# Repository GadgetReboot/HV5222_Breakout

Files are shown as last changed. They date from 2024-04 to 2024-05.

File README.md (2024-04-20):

# HV5222_Breakout
HV5222 32 bit shift register breakout board
<BR><BR>
Shield: [][cc-by-sa]

This work is licensed under a
[Creative Commons Attribution-ShareAlike 4.0 International License][cc-by-sa].

[][cc-by-sa]

[cc-by-sa]: http://creativecommons.org/licenses/by-sa/4.0/
[cc-by-sa-image]: https://licensebuttons.net/l/by-sa/4.0/88x31.png
[cc-by-sa-shield]: https://img.shields.io/badge/License-CC%20BY--SA%204.0-lightgrey.svg

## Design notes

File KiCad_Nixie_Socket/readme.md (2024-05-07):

This is the KiCad schematic for the IN-12 nixie tube breakout board and a pcb footprint for the nixie socket, which uses individual nixie socket pins available on ebay/AliExpress etc.  The pcb for the breakout board needs to be re-designed due to errors in the original.

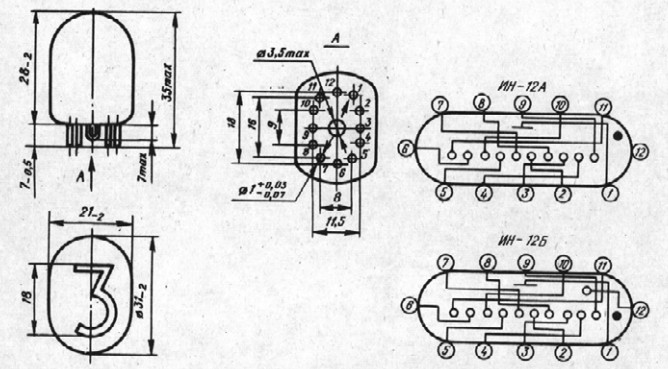
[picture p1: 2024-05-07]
KiCad_Nixie_Socket/pinout.jpg

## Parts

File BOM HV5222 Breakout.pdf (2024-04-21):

HV5222 Breakout BOM

Item # | Reference Designator | Qty | Manufacturer | Mfg Part # | Description / Value | Package/Footprint | Type | Instructions / Notes
1 | C3 | 1 | Samsung | CL21B104KBCNNWC | CAP CER 0.1UF 50V X7R 0805 | 0805 | SMD
2 | C1 C2 | 2 | Samsung | CL21B105KBFNNNE | CAP CER 1UF 50V X7R 0805 | 0805 | SMD
3 | D1 | 1 | SMC Diode Solutions | SS16 | 60V, 1A, SMA, DIODE SCHOTTKY | SMA | SMD
4 | J2 | 0 | | | | | | Do Not Install - User shall decide how to mount
5 | J1 J4 | 0 | | | | | | Do Not Install - User shall decide how to mount
6 | J3 | 0 | | | | | | Do Not Install - User shall decide how to mount
7 | L1 | 1 | Taiyo Yuden | NR6045T220M | FIXED IND 22UH 1.5A 149.5MOHM | Non Standard | SMD
8 | Q1 Q2 Q3 | 3 | Diotec Semiconductor | MMBT3904 | TRANS NPN 40V 200MA SOT23-3 | SOT23 | SMD
9 | R4 R7 R10 R12 | 4 | Panasonic | ERJ-6GEYJ472V | RES SMD 4K7 OHM 5% 1/8W 0805 | 0805 | SMD
10 | R2 | 1 | Panasonic | ERJ-6ENF1052V | RES SMD 10.5K OHM 1% 1/8W 0805 | 0805 | SMD
11 | R1 R3 R5 R6 R8 R9 R11 | 7 | Panasonic | ERJ-6ENF9102V | RES SMD 91K OHM 1% 1/8W 0805 | 0805 | SMD
12 | U1 | 1 | Diodes Incorporated | AP3012KTR-G1 | IC REG BOOST ADJ 500MA | SOT23-5 | SMD
13 | U2 | 1 | Microchip | HV5222PJ-G | IC 32BIT SRL PARALLEL 220V 44PLC | 44PLCC | SMD

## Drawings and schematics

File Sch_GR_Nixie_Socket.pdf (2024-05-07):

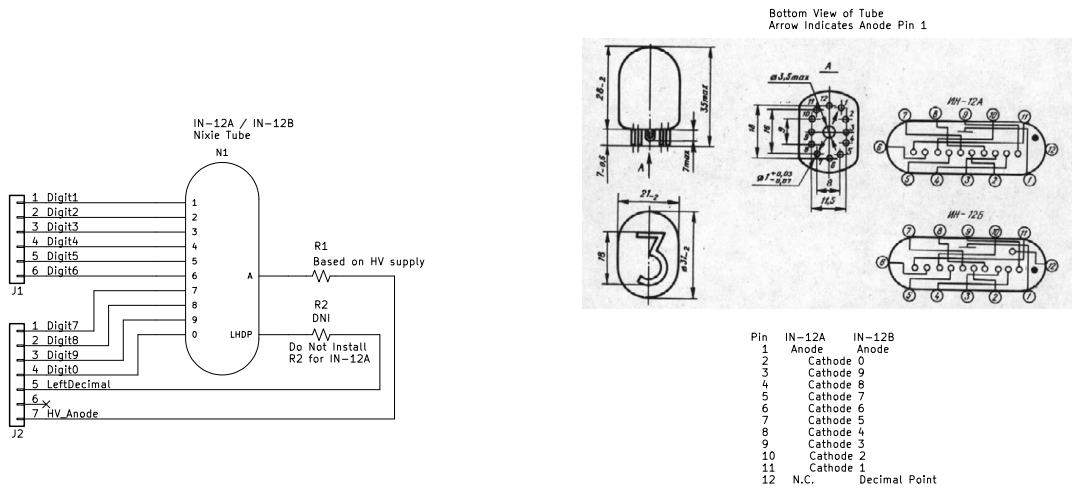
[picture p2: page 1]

https://github.com/GadgetReboot/HV5222_Breakout
https://www.youtube.com/gadgetreboot
File: GR_Nixie_Socket.sch Sheet: / Gadget Reboot

Id: 1/1 Title: Nixie Tube Socket IN-12A/B

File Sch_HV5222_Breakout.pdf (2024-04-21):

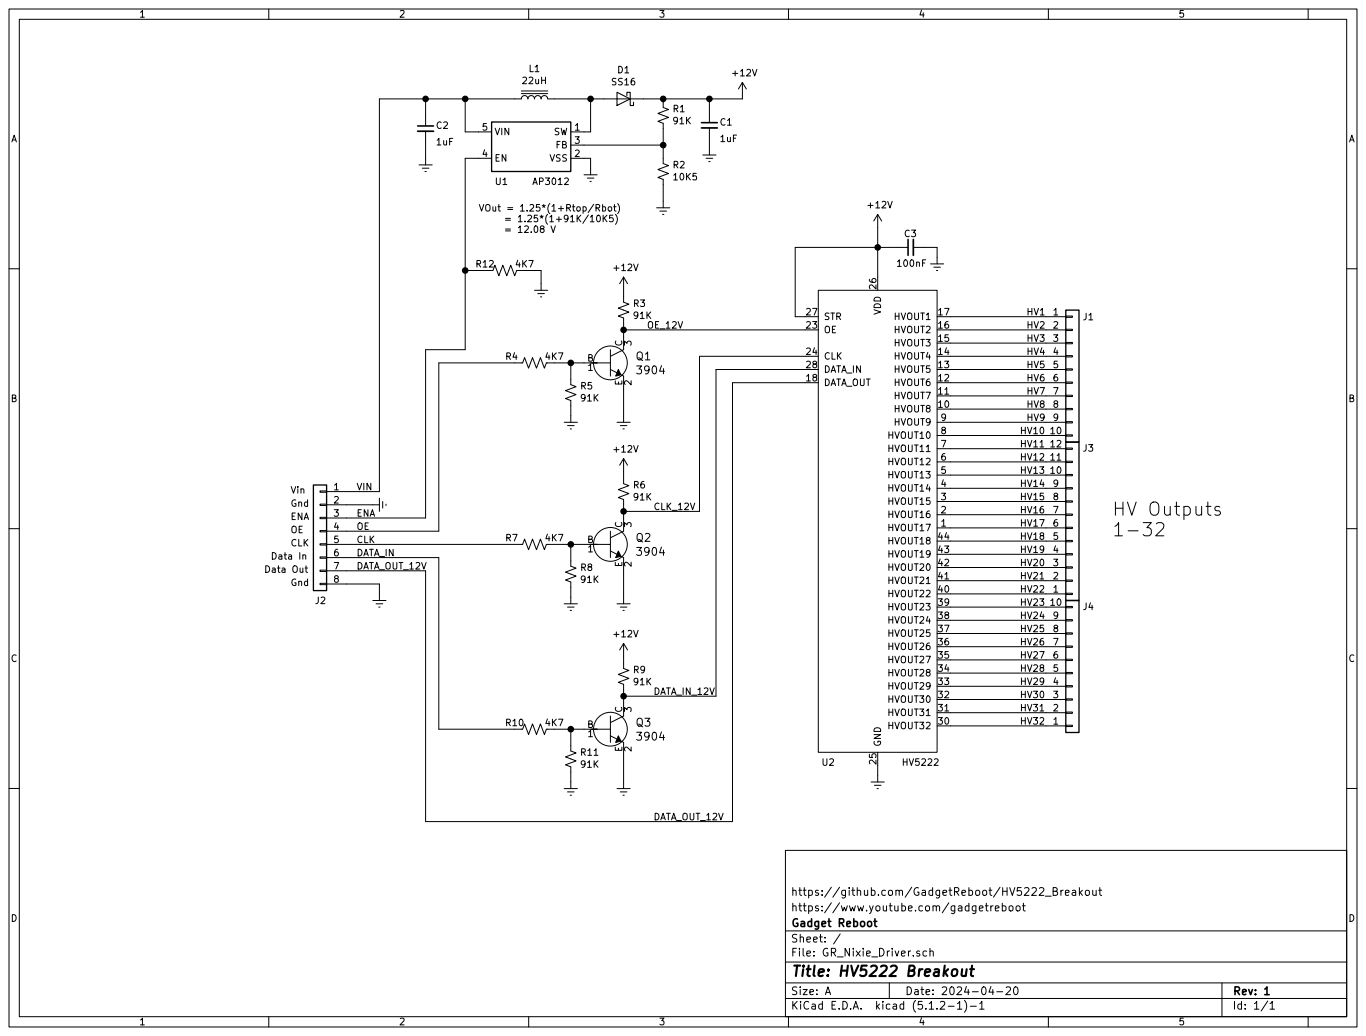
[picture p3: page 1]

https://github.com/GadgetReboot/HV5222_Breakout
https://www.youtube.com/gadgetreboot
File: GR_Nixie_Driver.sch Sheet: / Gadget Reboot

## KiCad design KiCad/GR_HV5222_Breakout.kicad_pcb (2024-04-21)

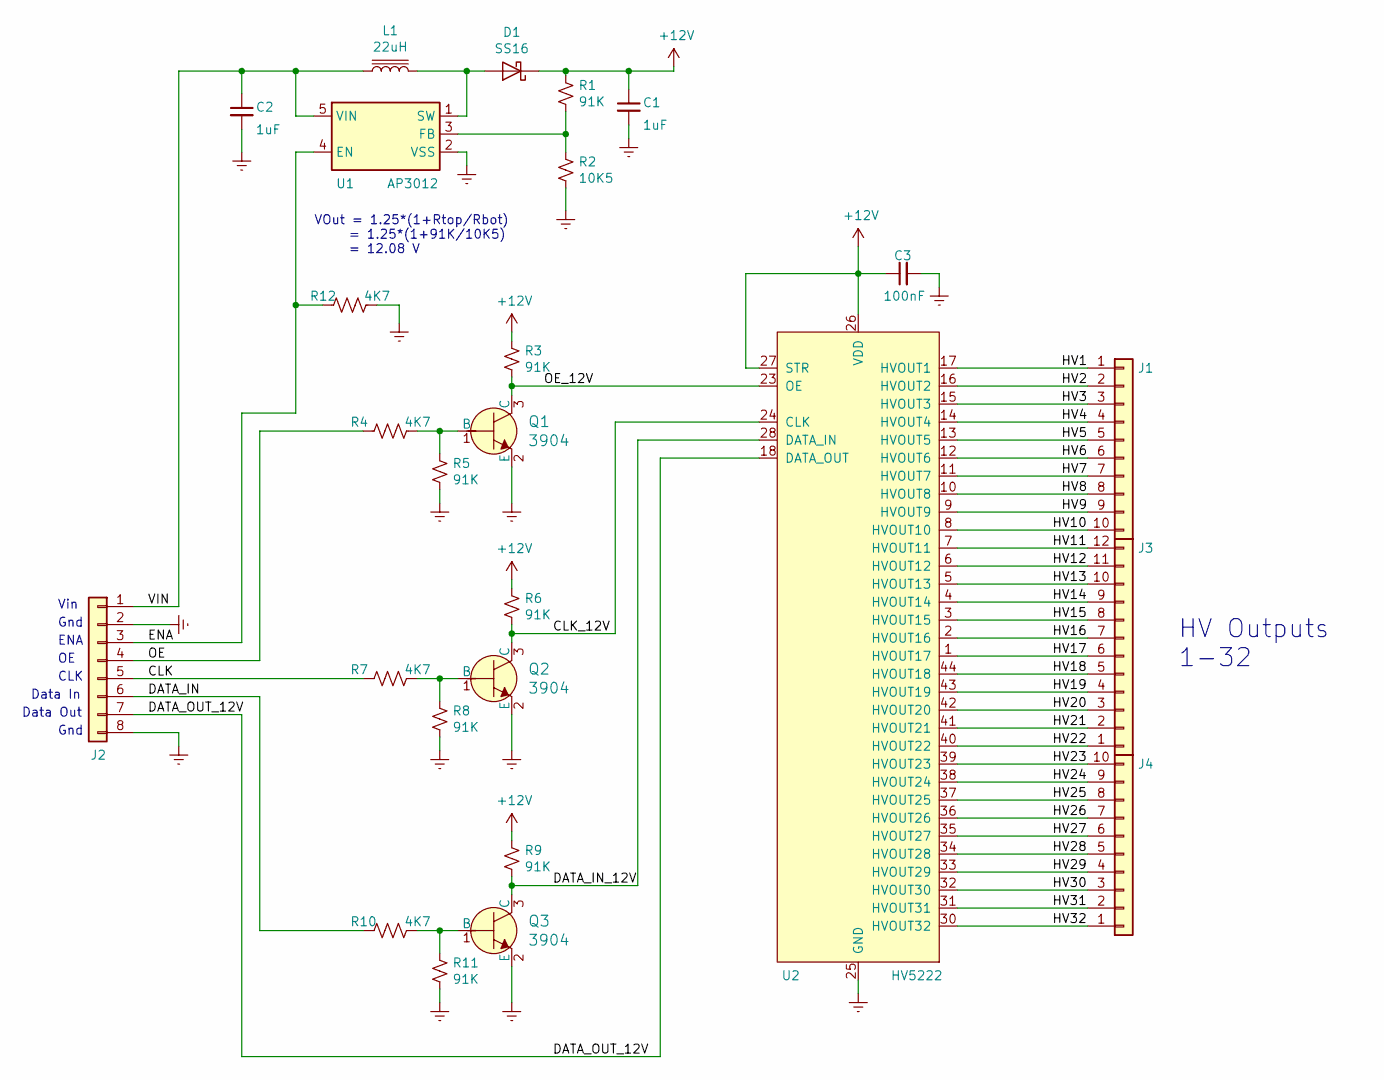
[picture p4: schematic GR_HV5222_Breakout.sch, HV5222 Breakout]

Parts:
C1, C2: 1uF; C_0805_2012Metric_Pad1.15x1.40mm_HandSolder; Part # CL21B105KBFNNNF
C3: 100nF; C_0805_2012Metric_Pad1.15x1.40mm_HandSolder; Part # CL21B105KBFNNNF
D1: SS16; D_SMA_Handsoldering; Part # SS16
J1, J4: Conn_01x10; PinHeader_1x10_P2.54mm_Vertical
J2: Conn_01x08; PinHeader_1x08_P2.54mm_Vertical
J3: Conn_01x12; PinHeader_1x12_P2.54mm_Vertical
L1: 22uH; L_Taiyo-Yuden_NR-60xx_HandSoldering; Part # NR6045T220M
Q1, Q2, Q3: 3904; SOT-23-3; MPN MMBT3904-TP; Digi-Key_PN MMBT3904TPMSCT-ND
R1, R3, R5, R6, R8, R9, R11: 91K; R_0805_2012Metric_Pad1.15x1.40mm_HandSolder
R2: 10K5; R_0805_2012Metric_Pad1.15x1.40mm_HandSolder
R4, R7, R10, R12: 4K7; R_0805_2012Metric_Pad1.15x1.40mm_HandSolder
U1: AP3012; SOT-23-5_HandSoldering
U2: HV5222; PLCC-44_16.6x16.6mm_P1.27mm

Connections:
+12V: C1.1, C3.1, D1.1 (K), R1.2, R3.2, R6.2, R9.2, U2.26 (VDD), U2.27 (STR)
/CLK: J2.5, R7.2
/CLK_12V: Q2.3 (C), R6.1, U2.24 (CLK)
/DATA_IN: J2.6, R10.2
/DATA_IN_12V: Q3.3 (C), R9.1, U2.28 (DATA_IN)
/DATA_OUT_12V: J2.7, U2.18 (DATA_OUT)
/ENA: J2.3, R12.2, U1.4 (EN)
/HV1: J1.1, U2.17 (HVOUT1)
/HV2: J1.2, U2.16 (HVOUT2)
/HV3: J1.3, U2.15 (HVOUT3)
/HV4: J1.4, U2.14 (HVOUT4)
/HV5: J1.5, U2.13 (HVOUT5)
/HV6: J1.6, U2.12 (HVOUT6)
/HV7: J1.7, U2.11 (HVOUT7)
/HV8: J1.8, U2.10 (HVOUT8)
/HV9: J1.9, U2.9 (HVOUT9)
/HV10: J1.10, U2.8 (HVOUT10)
/HV11: J3.12, U2.7 (HVOUT11)
/HV12: J3.11, U2.6 (HVOUT12)
/HV13: J3.10, U2.5 (HVOUT13)
/HV14: J3.9, U2.4 (HVOUT14)
/HV15: J3.8, U2.3 (HVOUT15)
/HV16: J3.7, U2.2 (HVOUT16)
/HV17: J3.6, U2.1 (HVOUT17)
/HV18: J3.5, U2.44 (HVOUT18)
/HV19: J3.4, U2.43 (HVOUT19)
/HV20: J3.3, U2.42 (HVOUT20)
/HV21: J3.2, U2.41 (HVOUT21)
/HV22: J3.1, U2.40 (HVOUT22)
/HV23: J4.10, U2.39 (HVOUT23)
/HV24: J4.9, U2.38 (HVOUT24)
/HV25: J4.8, U2.37 (HVOUT25)
/HV26: J4.7, U2.36 (HVOUT26)
/HV27: J4.6, U2.35 (HVOUT27)
/HV28: J4.5, U2.34 (HVOUT28)
/HV29: J4.4, U2.33 (HVOUT29)
/HV30: J4.3, U2.32 (HVOUT30)
/HV31: J4.2, U2.31 (HVOUT31)
/HV32: J4.1, U2.30 (HVOUT32)
/OE: J2.4, R4.2
/OE_12V: Q1.3 (C), R3.1, U2.23 (OE)
/VIN: C2.1, J2.1, L1.1, U1.5 (VIN)
GNDREF: C1.2, C2.2, C3.2, J2.2, J2.8, Q1.2 (E), Q2.2 (E), Q3.2 (E), R2.1, R5.1, R8.1, R11.1, R12.1, U1.2 (VSS), U2.25 (GND)
unnamed: D1.2 (A), L1.2, U1.1 (SW)
unnamed: Q1.1 (B), R4.1, R5.2
unnamed: Q2.1 (B), R7.1, R8.2
unnamed: Q3.1 (B), R10.1, R11.2
unnamed: R1.1, R2.2, U1.3 (FB)

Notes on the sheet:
VOut = 1.25*(1+Rtop/Rbot) = 1.25*(1+91K/10K5) = 12.08 V
Vin
Gnd
CLK
Data In
Data Out
HV Outputs 1-32
ENA

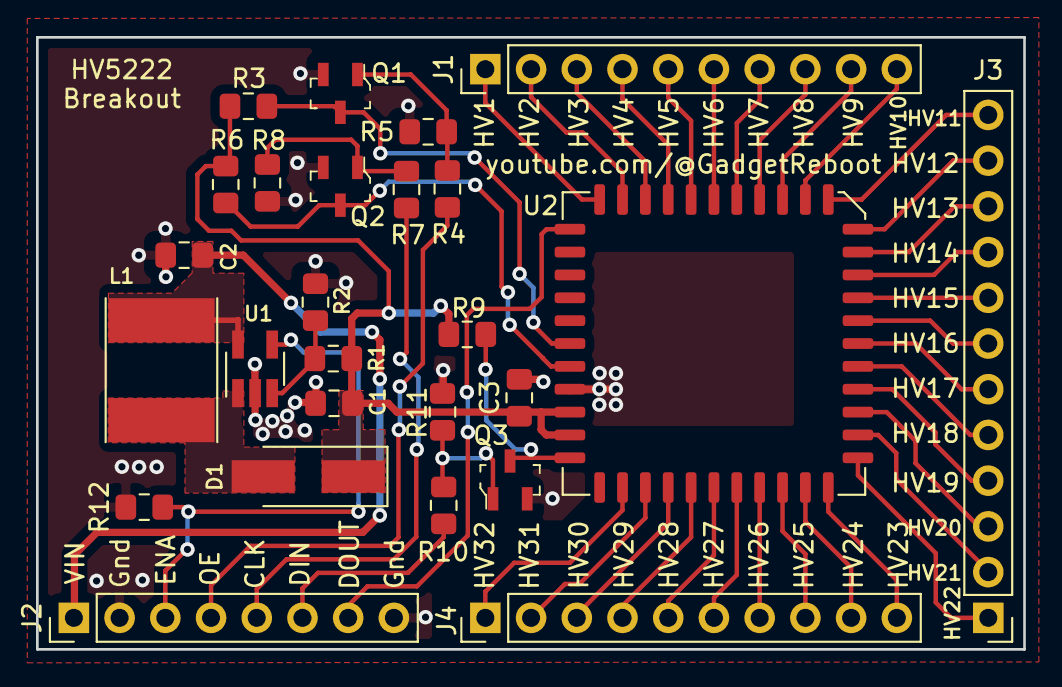
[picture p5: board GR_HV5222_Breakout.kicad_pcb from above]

Board: 2 copper layers, 54.8 x 34.0 mm, 26 parts (0 on the bottom side), 48 nets.

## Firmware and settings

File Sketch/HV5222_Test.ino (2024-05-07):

/*
  HV5222 Driver Test
  Uses Nano to clock 32 bits of data into HV5222
  Data value "1" turns on a driver output (bringing it to ground)
  Data value "0" turns off a driver output

  The driver output enable and 12v power supply must be controlled properly to prevent
  unexpected driver output states during power up and while clocking data in.

  Gadget Reboot

*/

int datapin = 2;            // driver data
int clk = 3;                // driver clock
int oe = 4;                 // driver output enable
int Ena12v = 5;             // 12v power supply enable (active high)
const byte maxCh = 32;      // 32 channel shift register
const int shiftDelay = 50;  // microsecond delay to use for shifting data

// turn all channels off
void clearOutputs() {
  disableOutput();
  digitalWrite(datapin, HIGH);
  delayMicroseconds(shiftDelay);
  for (byte i = 0; i < 32; i++) {    // send data=0 to all driver channels to turn them off
    toggleClk();
  }
  enableOutput();
}

// set driver OE low (hardware inverted logic, so gpio is set high) to disable driver output pins
void disableOutput() {
  delayMicroseconds(shiftDelay);
  digitalWrite(oe, HIGH);
  delayMicroseconds(shiftDelay);
}

// set driver OE high (hardware inverted logic, so gpio is set low) to enable driver output pins
void enableOutput() {
  delayMicroseconds(shiftDelay);
  digitalWrite(oe, LOW);
  delayMicroseconds(shiftDelay);
}

// set clock low, then high to shift in a data bit (hardware has inverted logic)
void toggleClk() {
  delayMicroseconds(shiftDelay);
  digitalWrite(clk, HIGH);
  delayMicroseconds(shiftDelay);
  digitalWrite(clk, LOW);
  delayMicroseconds(shiftDelay);
}

void setCh( int ch, boolean state ) {

  Serial.print("Turning output ch ");
  Serial.print(ch);
  Serial.println(state ? " On" : " Off");
  boolean chState = !state;              // invert the control signal since hardware is inverted

  disableOutput();
  //set the target channel state and set all other channels off
  if (ch > 1 && ch < 32) {
    digitalWrite(datapin, HIGH);            // turn off any channels after target channel eg. turn off ch7-32  if targeting ch6
    for (byte i = maxCh; i > ch; i--) {
      toggleClk();
    }
  }

  digitalWrite(datapin, chState);           // control the target channel as requested
  toggleClk();

  digitalWrite(datapin, HIGH);            // turn off any channels before target channel eg. turn off ch1-5  if targeting ch6
  for (byte i = ch; i > 1; i--) {
    toggleClk();
  }
  enableOutput();
}

// turn on one channel at a time to test all outputs
void walkingOneTest() {
  for (byte i = 1; i <= 32; i++) {
    setCh(i, true);
    delay(300);
  }
}

void displayNumber(int num) {
  //separate the digits out of the integer
  byte ones = num % 10;
  byte tens = (num / 10) % 10;
  byte hund = (num / 100) % 10;

  Serial.print("Number ");
  Serial.println(num);

  Serial.print("Ones ");
  Serial.print(ones);

  Serial.print(" Tens ");
  Serial.print(tens);

  Serial.print(" Hundreds ");
  Serial.println(hund);

  byte hvChannel[32];  // array of on/off data for HV outputs
  for (int i = 0; i <= 31; i++) {  // make sure array is init with all 0
    hvChannel[i] = 0;
  }

  // set a bit for each digit that will be turned on
  // Hundreds [0..9] = HV output [1..10]
  // Tens     [0..9] = HV output [11..20]
  // Ones     [0..9] = HV output [21..30]

  // Add 20 to the Ones digit value to jump to that part of the array
  // and set a bit to turn on a digit
  hvChannel[ones + 20] = 1;

  // if the tens digit is needed, add array position offset 10 and control that digit (don't show leading zeros)
  if (num > 9) hvChannel[tens + 10] = 1;

  // if the hundreds digit is needed, (no array offset needed) control that digit (don't show leading zeros)
  if (num > 99) hvChannel[hund] = 1;

  Serial.println("HV Output Pins [32..1]");

  // shift the array data to the HV driver in the correct order for the shift register to decode, and turn on the outputs
  disableOutput();
  for (int i = 31; i >= 0; i--) {
    boolean dataVal;
    if (hvChannel[i] == 0)
      dataVal = HIGH;
    else
      dataVal = LOW;
    digitalWrite(datapin, dataVal); // turn HV channels on or off (inverted hardware logic) based on array data
    toggleClk();
  }
  enableOutput();

  for (int i = 31; i >= 0; i--) {
    boolean dataVal;
    if (hvChannel[i] == 0)
      dataVal = HIGH;
    else
      dataVal = LOW;
    Serial.print(dataVal ? "1" : "0");
  }
  Serial.println();
  Serial.println();
}

void setup() {
  // set driver control signals (high gpio = low signal after transistor driver for clk, datapin, oe)
  digitalWrite(datapin, HIGH);
  digitalWrite(clk, LOW);      // keep clock high until time to shift data in on falling edge of clock
  digitalWrite(oe, HIGH);      // keep driver outputs disabled until data has been shifted in
  digitalWrite(Ena12v, HIGH);  // enable driver 12v power supply so HV5222 can power up with outputs disabled (oe pin)
  pinMode(oe, OUTPUT);
  pinMode(datapin, OUTPUT);
  pinMode(clk, OUTPUT);
  pinMode(Ena12v, OUTPUT);

  Serial.begin(115200);

  Serial.println("Setup: Clear outputs");
  clearOutputs();  // set all driver outputs to off
}

void loop() {

  //walkingOneTest();  // turn on one driver output at a time to test all 32 channels


  // count from 0 to 999 using 3 Nixie IN-12 digits
  // output 1-10 = Hundreds digit 0-9
  // output 11-20 = Tens digit 0-9
  // output 21-30 = Ones digit 0-9

  for (int i = 0; i <= 999; i++) {
    displayNumber(i);
    delay(300);
  }


}

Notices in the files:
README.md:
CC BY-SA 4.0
